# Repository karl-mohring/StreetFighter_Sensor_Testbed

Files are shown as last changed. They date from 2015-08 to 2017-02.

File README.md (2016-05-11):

# StreetFighter - Smart Streetlight Testbed


License (http://www.gnu.org/licenses/gpl-3.0.en.html)

# What is it?
StreetFighter is a smart cities sensor platform intended for mounting inside LED street lights. The platform includes sensors to monitor road usage, and can manage street light dimming to adapt the light level to real-time traffic.

Streetfighter installed in LED streetlight

## Why the stupid name?
- The main hardware platform of this project is the Arduino **Yun**.
- **Yun** (Lee) is a character from CAPCOM's **Street Fighter** franchise.
- Our sensor platform is intended for road-side deployment in **street** lights to **fight** energy waste
- It made sense to me...

# [Quick Start](https://github.com/Leenix/StreetFighter_Sensor_Testbed/wiki/Hardware-Installation)
The phrase "quick-start" can be misleading in hardware projects, but here's a list of things you'll need to set up this platform [(Full details in the Wiki)](https://github.com/Leenix/StreetFighter_Sensor_Testbed/wiki):
- Arduino Yun (with 4GB card) or Arduino Leonardo (for the non-logging, non-WiFi version)
- StreetFighter PCB
- Traffic sensors (sonar, lidar, PIR)
- Environmental sensors (temperature, humidity, illuminance, IR temperature, noise)
- Some kind of long-range network transceiver (XBee socket)

After you get all all that, you just need to populate the PCBs, wire up the sensors, configure the Yun software, build and upload the Arduino-side firmware, power the platform somehow, and then you're golden.

# [Features](https://github.com/Leenix/StreetFighter_Sensor_Testbed/wiki/Features)
## Traffic detection
- PIR sensor detects generic movements from vehicles, cyslists, and pedestrians
- Sonar/Lidar counts vehicles over a single lane

## Environmental monitoring
- Ambient temperature
- Relative humidity
- Illuminance
- Ambient noise
- Road temperature
- Road flood level

## Lamp health and control
- Luminaire temperature
- Power consumption
- Dimming interface

## Other
- Smartphone detection using Wifi and/or Bluetooth
- Public WiFi AP (if wired connection is provided)

# [Documentation](https://github.com/Leenix/StreetFighter_Sensor_Testbed/wiki)
- Full installation documentation can be found on the [Wiki](https://github.com/Leenix/StreetFighter_Sensor_Testbed/wiki)
- Code documentation is inside the code. No external reference just yet.

# [License](http://www.gnu.org/licenses/gpl-3.0.en.html)

This project is licensed under the terms of the GNU General Public License v3.0.

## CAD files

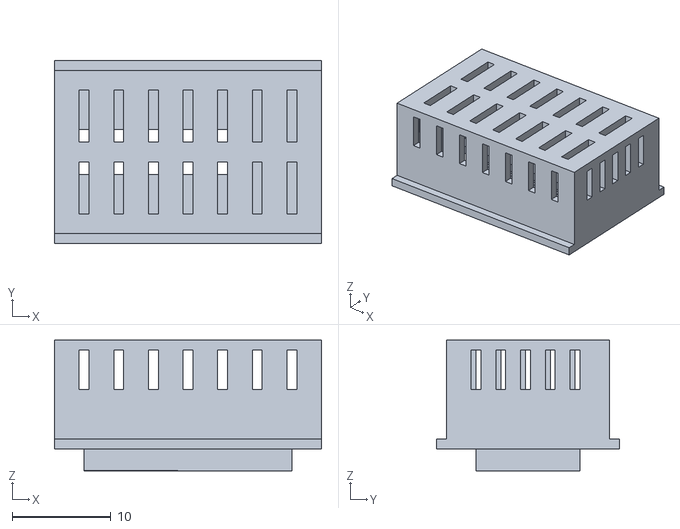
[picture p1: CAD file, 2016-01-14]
CAD/HIH screen.stl
27.0 x 18.5 x 13.2

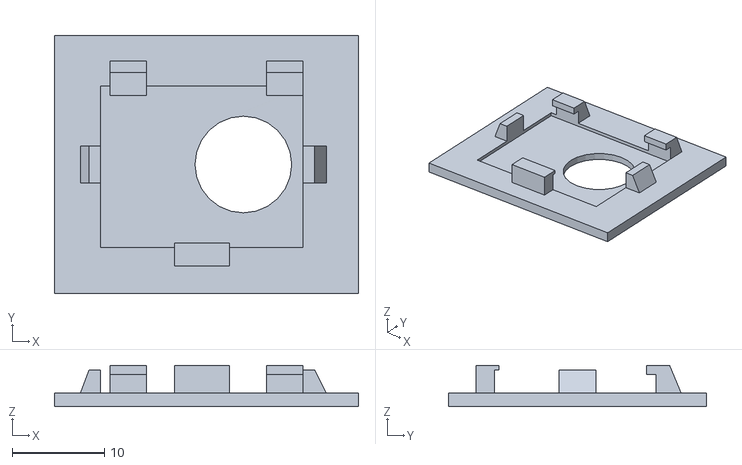
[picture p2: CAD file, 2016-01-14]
CAD/Individual sensor mounts/MIC mount.stl
33.0 x 28.0 x 4.50

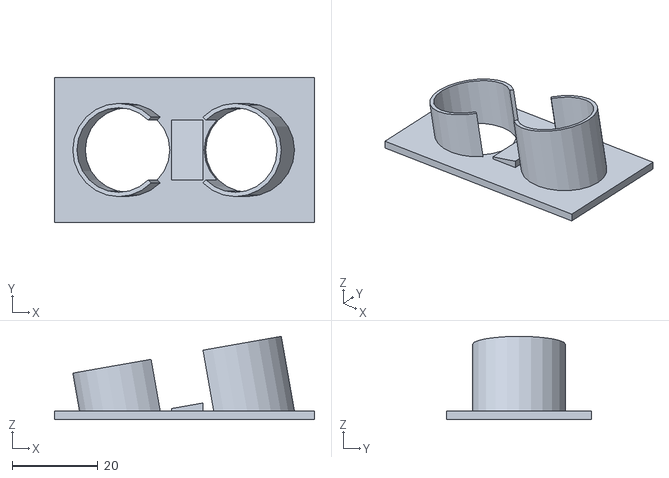
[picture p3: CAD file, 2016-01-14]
CAD/Luminaire Case/Lidar mount.stl
60.6 x 33.7 x 19.4

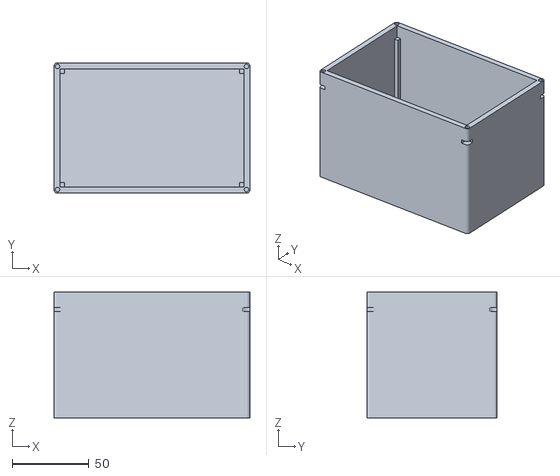
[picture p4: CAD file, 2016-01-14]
CAD/Individual sensor mounts/Streetfighter_casing.stl
128.0 x 85.0 x 82.0

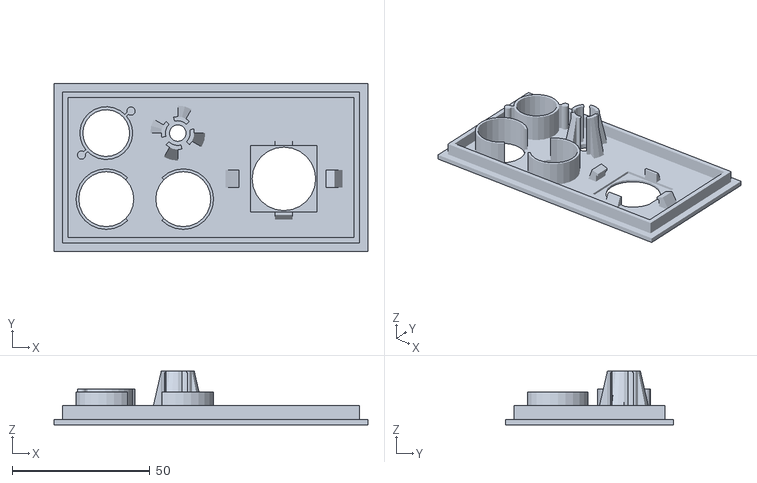
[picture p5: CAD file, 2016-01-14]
CAD/Luminaire Case/Big shell.stl
114.2 x 61.0 x 19.5

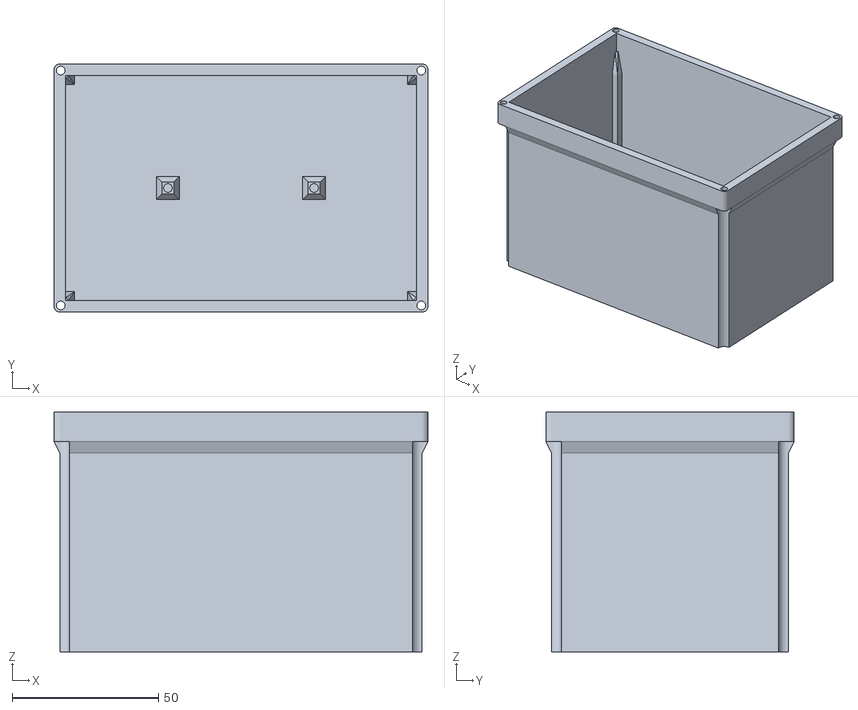
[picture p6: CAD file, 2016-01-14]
CAD/Individual sensor mounts/Streetfighter_casing-v3.stl
128.0 x 85.0 x 82.0

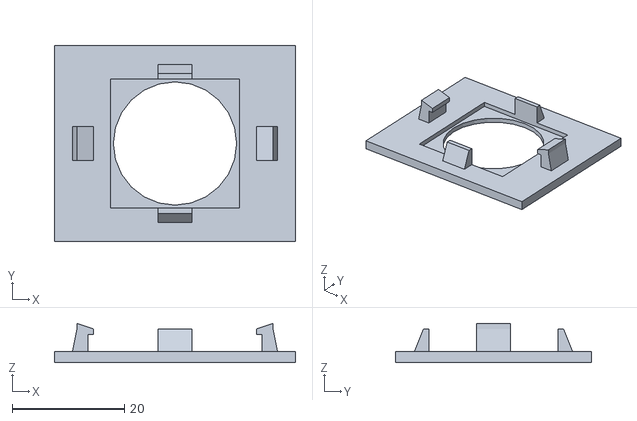
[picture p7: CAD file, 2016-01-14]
CAD/Individual sensor mounts/PIR Mount.stl
43.0 x 35.0 x 7.00

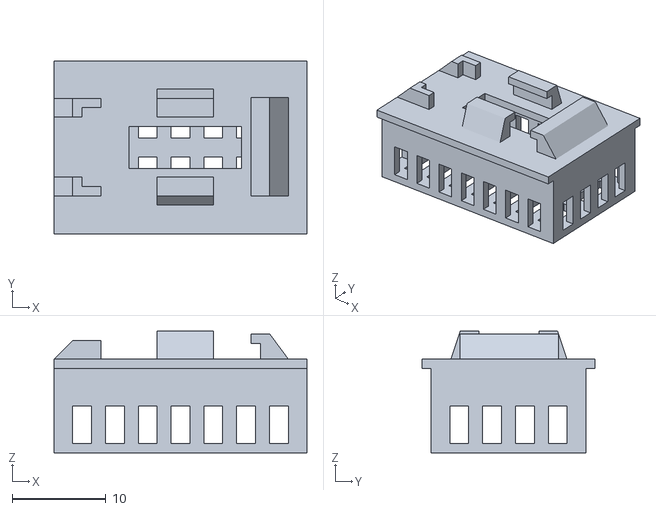
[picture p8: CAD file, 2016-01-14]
CAD/Individual sensor mounts/HIH screen.stl
27.0 x 18.5 x 13.0

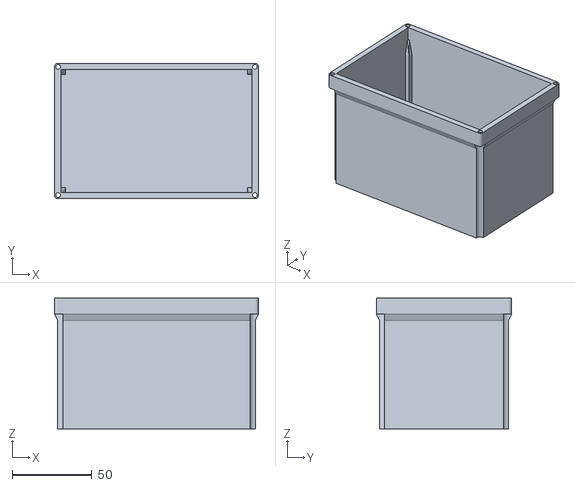
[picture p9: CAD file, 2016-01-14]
CAD/Individual sensor mounts/Streetfighter_casingv1.stl
128.0 x 85.0 x 82.0

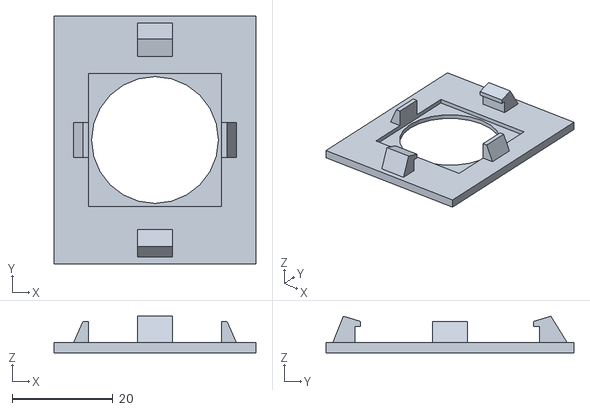
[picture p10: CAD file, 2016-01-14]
CAD/Individual sensor mounts/PIR Mount v2.stl
40.1 x 49.3 x 7.28

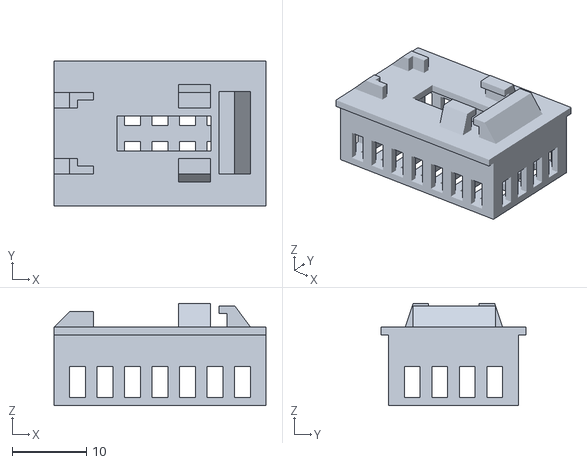
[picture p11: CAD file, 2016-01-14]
CAD/Individual sensor mounts/HIH4030 screen.stl
28.6 x 19.6 x 13.8

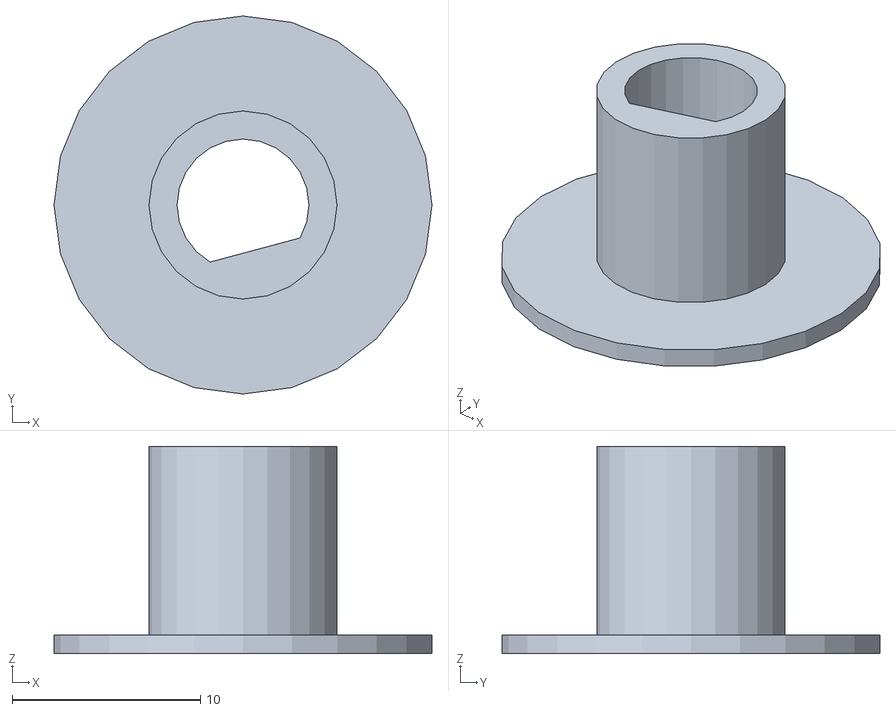
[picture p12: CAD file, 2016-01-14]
CAD/Individual sensor mounts/TMP36 Mount.stl
20.1 x 20.1 x 11.0

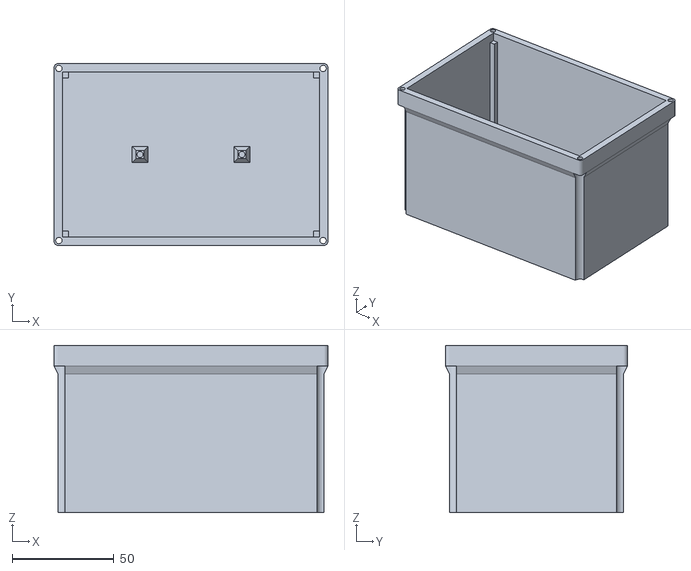
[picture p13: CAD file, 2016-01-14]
CAD/Individual sensor mounts/Streetfighter_casingv4.stl
134.4 x 89.3 x 82.0

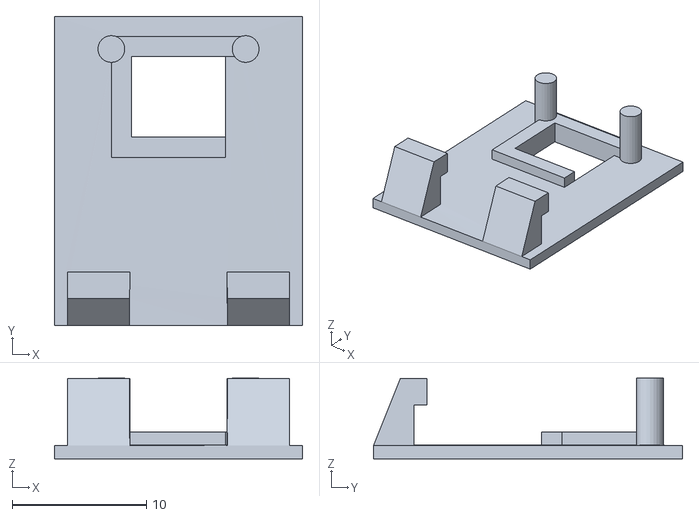
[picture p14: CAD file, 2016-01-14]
CAD/Individual sensor mounts/BH1750_mount.stl
18.5 x 23.0 x 6.02

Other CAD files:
CAD/Individual sensor mounts/Streetfighter_casing-v2.stl
CAD/Individual sensor mounts/BH1750_mount.skp
CAD/Individual sensor mounts/EZ0 Mount.skp
CAD/Individual sensor mounts/HIH screen.skp
CAD/Individual sensor mounts/HIH4030 screen.skp
CAD/Individual sensor mounts/Lidar mount.skp
CAD/Individual sensor mounts/MIC mount + spring.skp
CAD/Individual sensor mounts/MIC mount.skp
CAD/Individual sensor mounts/MIC mount1.skp
CAD/Individual sensor mounts/MLX90614 Mount.skp
CAD/Individual sensor mounts/PIR Mount.skp
CAD/Individual sensor mounts/Streetfighter_casing.skp
CAD/Individual sensor mounts/Streetfighter_casingv1.skp
CAD/Individual sensor mounts/Streetfighter_faceplate1.skp
CAD/Individual sensor mounts/Streetfighter_faceplate2.skp
CAD/Individual sensor mounts/TMP36 Mount.skp
CAD/Luminaire Mounting Plates.skp

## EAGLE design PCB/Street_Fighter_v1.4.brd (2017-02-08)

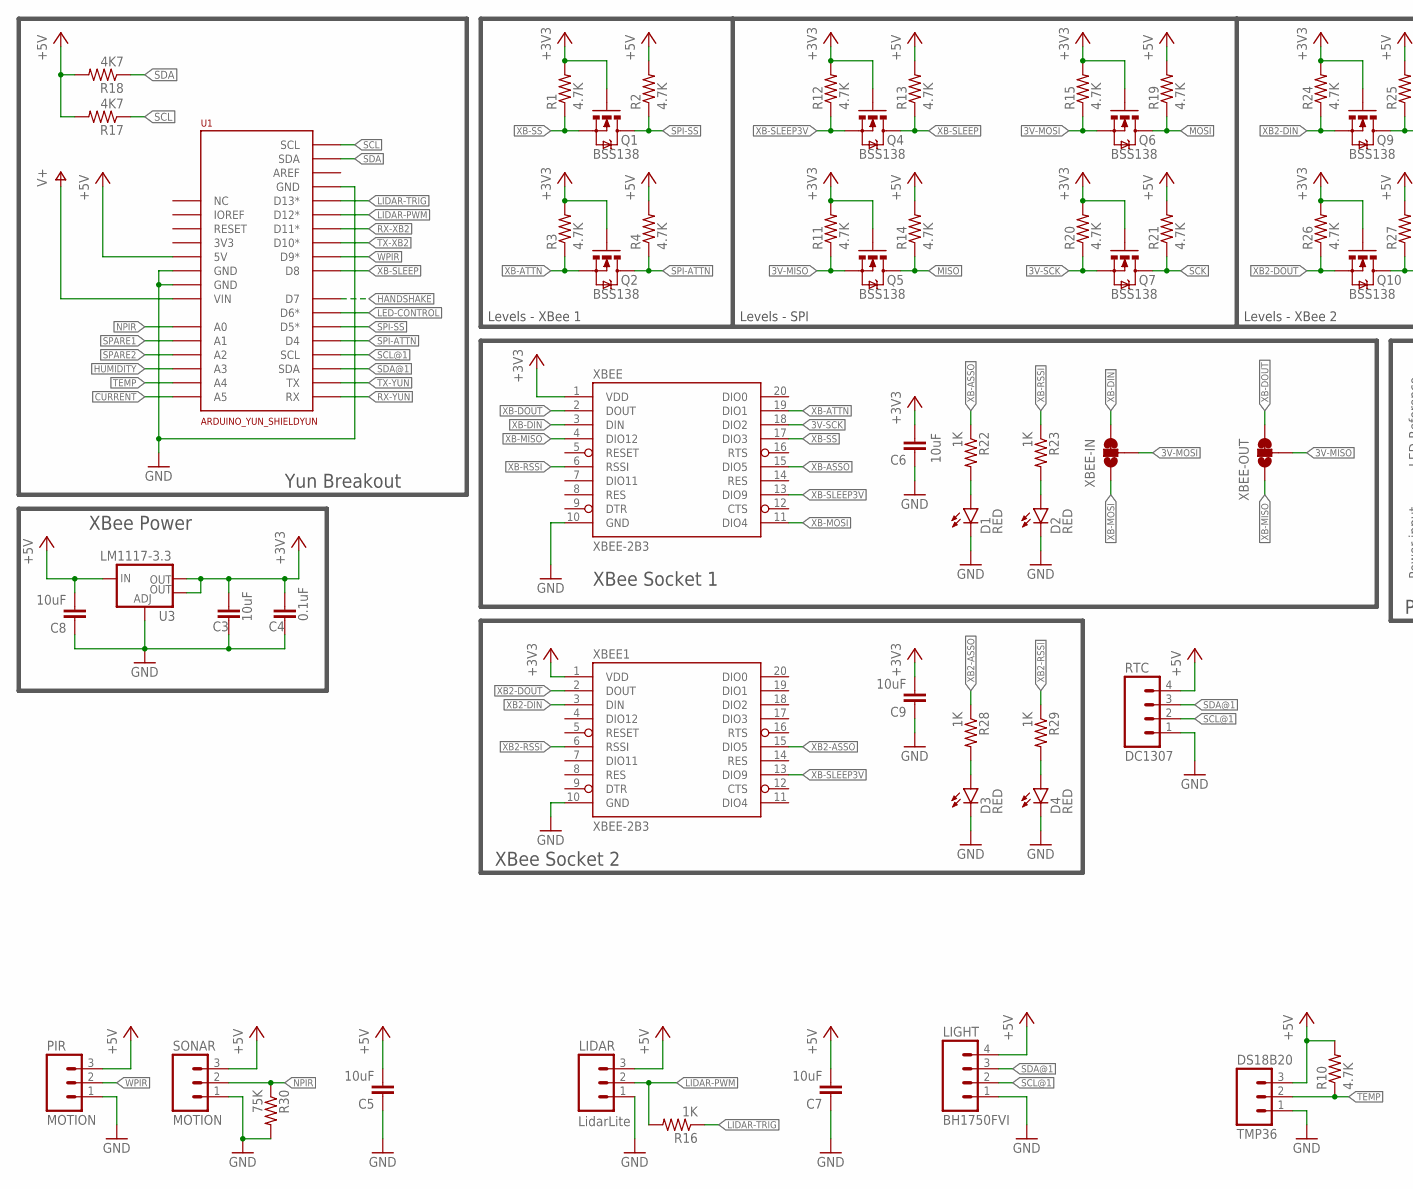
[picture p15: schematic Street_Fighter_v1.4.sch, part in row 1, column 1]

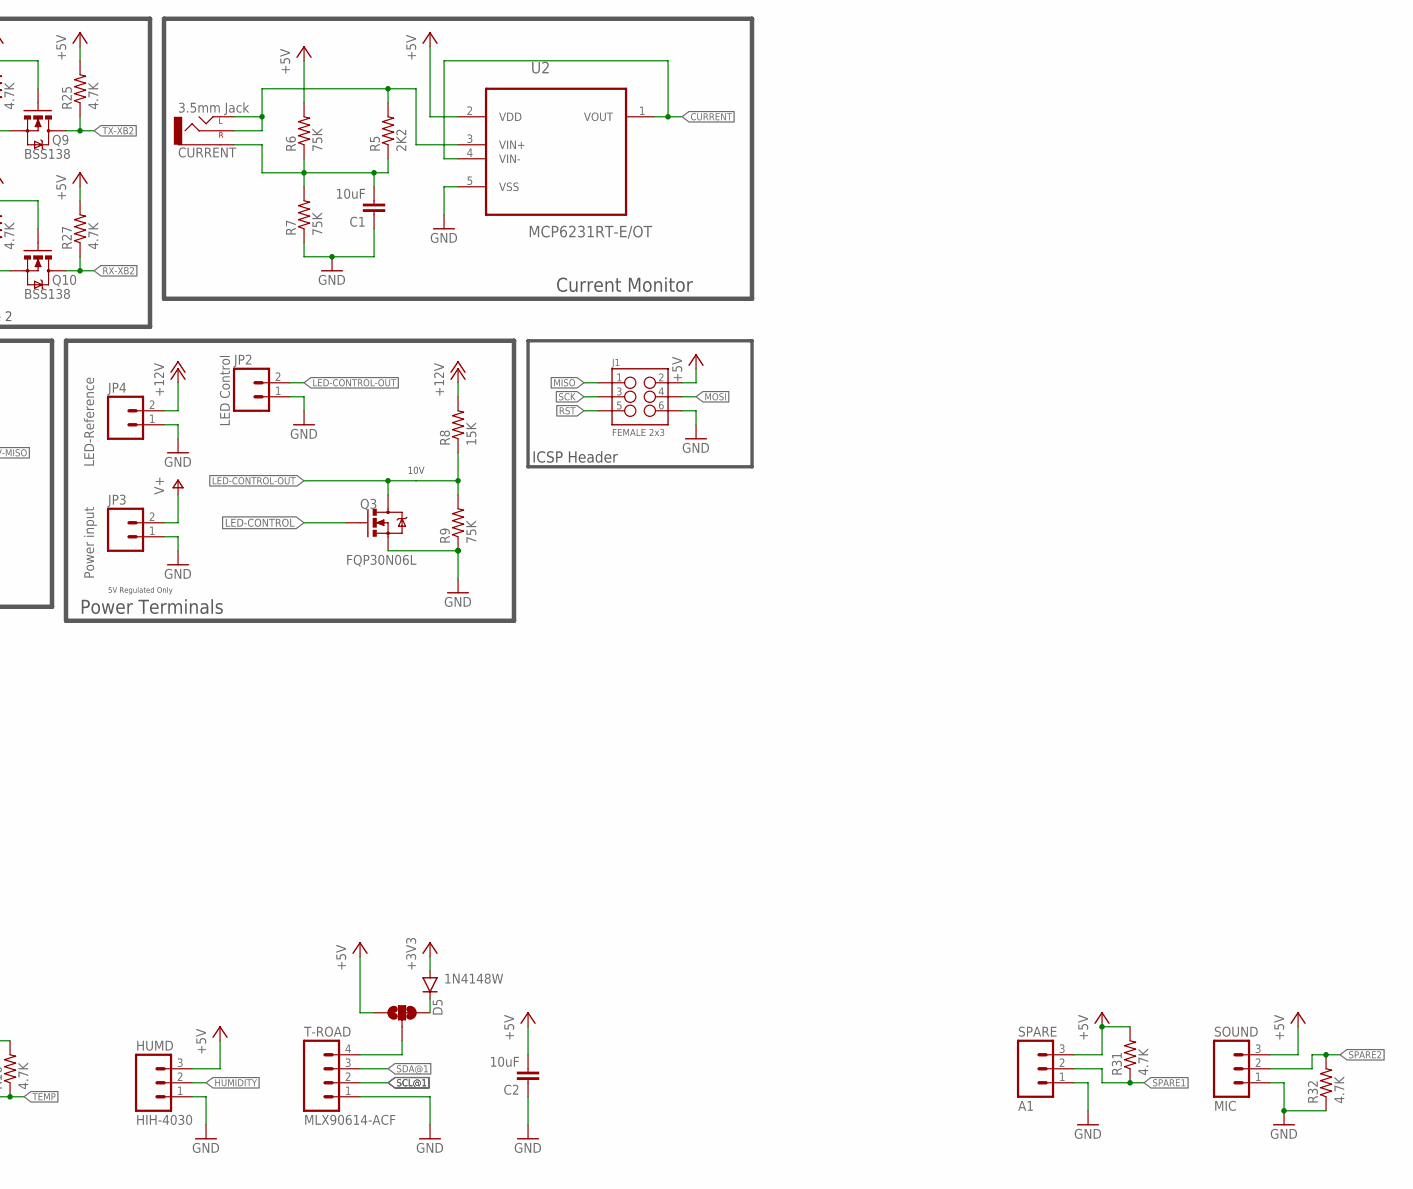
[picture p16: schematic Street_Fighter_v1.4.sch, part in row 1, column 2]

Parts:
C1, C2, C3, C5, C6, C7, C8, C9: 10uF; 1206
C4: 0.1uF; 1206
CURRENT: 3.5mm Jack; AUDIO-JACK
D1, D2, D3, D4: RED; LED-1206
D5: 1N4148W; SOD-123
DS18B20: TMP36; 1X03
HUMD: HIH-4030; 1X03
J1: FEMALE 2x3; 2X3
JP2: LED Control; 1X02_LONGPADS
JP3: Power input; 1X02_LONGPADS
JP4: LED-Reference; 1X02_LONGPADS
LIDAR: LidarLite; 1X03
LIGHT: BH1750FVI; 1X04
PIR: MOTION; 1X03
Q1, Q2, Q4, Q5, Q6, Q7, Q9, Q10: BSS138; SOT23
Q3: FQP30N06L; TO220V
R1, R2, R3, R4, R10, R11, R12, R13, R14, R15, R19, R20, R21, R24, R25, R26, R27, R31, R32: 4.7K; 1206
R5: 2K2; 1206
R6, R7, R9, R30: 75K; 1206
R8: 15K; 1206
R16, R22, R23, R28, R29: 1K; 1206
R17, R18: 4K7; 1206
RTC: DC1307; 1X04
SONAR: MOTION; 1X03
SOUND: MIC; 1X03
SPARE: A1; 1X03
T-ROAD: MLX90614-ACF; 1X04
U1: ARDUINO_YUN_SHIELDYUN; DUEMILANOVE_VIAS
U2: MCP6231RT-E/OT; SOT95P270X145-5N
U3: LM1117-3.3; SOT223
XBEE, XBEE1: XBEE-2B3; XBEE-SMD
XBEE-IN: JUMPER-PAD-3-2OF3_NC_BY_TRACE_SMALL; PAD-JUMPER-3-2OF3_NC_BY_TRACE_YES_SILK_FULL_BOX
XBEE-OUT, XBEE-OUT1: JUMPER-PAD-3-2OF3_NC_BY_TRACE_SMALL; PAD-JUMPER-3-2OF3_NC_BY_TRACE_YES_SILK_FULL_BOX

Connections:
3V3: U1.3V3
3V-MISO: Q5.2 (S), R11.1, XBEE-OUT.2
3V-MOSI: Q6.2 (S), R15.1, XBEE-IN.2
3V-SCK: Q7.2 (S), R20.1, XBEE.18 (DIO2)
+3V3: C3.2, C4.2, C6.2, C9.2, D5.A, Q1.1 (G), Q2.1 (G), Q4.1 (G), Q5.1 (G), Q6.1 (G), Q7.1 (G), Q9.1 (G), Q10.1 (G), R1.2, R3.2, R11.2, R12.2, R15.2, R20.2, R24.2, R26.2, U3.2 (OUT), U3.4 (OUT), XBEE.1 (VDD), XBEE1.1 (VDD)
+5V: C2.2, C5.2, C7.2, C8.2, DS18B20.3, HUMD.3, J1.2, LIDAR.3, LIGHT.4, PIR.3, R2.2, R4.2, R6.2, R10.2, R13.2, R14.2, R17.2, R18.2, R19.2, R21.2, R25.2, R27.2, R31.2, RTC.4, SONAR.3, SOUND.3, SPARE.3, U1.5V, U2.2 (VDD), U3.3 (IN), XBEE-OUT1.1
+12V: JP4.2, R8.2
CURRENT: U1.A5, U2.1 (VOUT), U2.4 (VIN-)
GND: C1.1, C2.1, C3.1, C4.1, C5.1, C6.1, C7.1, C8.1, C9.1, D1.C, D2.C, D3.C, D4.C, DS18B20.1, HUMD.1, J1.6, JP2.1, JP3.1, JP4.1, LIDAR.1, LIGHT.1, PIR.1, Q3.3 (S), R7.1, R9.1, R30.2, R32.1, RTC.1, SONAR.1, SOUND.1, SPARE.1, T-ROAD.1, U1.GND, U1.GND@0 (GND), U1.GND@1 (GND), U2.5 (VSS), U3.1 (ADJ), XBEE.10 (GND), XBEE1.10 (GND)
HANDSHAKE: U1.7 (D7)
HUMIDITY: HUMD.2, U1.A3
LED-CONTROL: Q3.1 (G), U1.6 (D6*)
LED-CONTROL-OUT: JP2.2, Q3.2 (D), R8.1, R9.2
LIDAR-PWM: LIDAR.2, R16.2, U1.12 (D12*)
LIDAR-TRIG: R16.1, U1.13 (D13*)
MISO: J1.1, Q5.3 (D), R14.1
MOSI: J1.4, Q6.3 (D), R19.1
unnamed: D1.A, R22.2
unnamed: CURRENT.RING (RIGHT), CURRENT.TIP (LEFT), R5.2, U2.3 (VIN+)
unnamed: D2.A, R23.2
unnamed: C1.2, CURRENT.SLEEVE, R5.1, R6.1, R7.2
unnamed: D3.A, R28.2
unnamed: D4.A, R29.2
unnamed: D5.C, XBEE-OUT1.3
unnamed: T-ROAD.4, XBEE-OUT1.2
NPIR: R30.1, SONAR.2, U1.A0
RST: J1.5
RX-XB2: Q10.3 (D), R27.1, U1.11 (D11*)
RX-YUN: U1.0 (RX)
SCK: J1.3, Q7.3 (D), R21.1
SCL: R17.1, U1.3@1 (SCL)
SCL@1: LIGHT.2, RTC.2, T-ROAD.2, U1.3 (SCL)
SDA: R18.1, U1.2@1 (SDA)
SDA@1: LIGHT.3, RTC.3, T-ROAD.3, U1.2 (SDA)
SPARE1: R31.1, SPARE.2, U1.A1
SPARE2: R32.2, SOUND.2, U1.A2
SPI-ATTN: Q2.3 (D), R4.1, U1.D4
SPI-SS: Q1.3 (D), R2.1, U1.5 (D5*)
TEMP: DS18B20.2, R10.1, U1.A4
TX-XB2: Q9.3 (D), R25.1, U1.10 (D10*)
TX-YUN: U1.1 (TX)
V+: JP3.2, U1.VIN
WPIR: PIR.2, U1.9 (D9*)
XB2-ASSO: R28.1, XBEE1.15 (DIO5)
XB2-DIN: Q9.2 (S), R24.1, XBEE1.3 (DIN)
XB2-DOUT: Q10.2 (S), R26.1, XBEE1.2 (DOUT)
XB2-RSSI: R29.1, XBEE1.6 (RSSI)
XB-ASSO: R22.1, XBEE.15 (DIO5)
XB-ATTN: Q2.2 (S), R3.1, XBEE.19 (DIO1)
XB-DIN: XBEE.3 (DIN), XBEE-IN.3
XB-DOUT: XBEE.2 (DOUT), XBEE-OUT.3
XB-MISO: XBEE.4 (DIO12), XBEE-OUT.1
XB-MOSI: XBEE.11 (DIO4), XBEE-IN.1
XB-RSSI: R23.1, XBEE.6 (RSSI)
XB-SLEEP: Q4.3 (D), R13.1, U1.8 (D8)
XB-SLEEP3V: Q4.2 (S), R12.1, XBEE.13 (DIO9), XBEE1.13 (DIO9)
XB-SS: Q1.2 (S), R1.1, XBEE.17 (DIO3)

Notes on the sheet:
10V
Power Terminals
Yun Breakout
Current Monitor
XBee Socket 1
5V Regulated Only
Levels - XBee 1
Levels - SPI
Levels - XBee 2
XBee Power
XBee Socket 2
ICSP Header

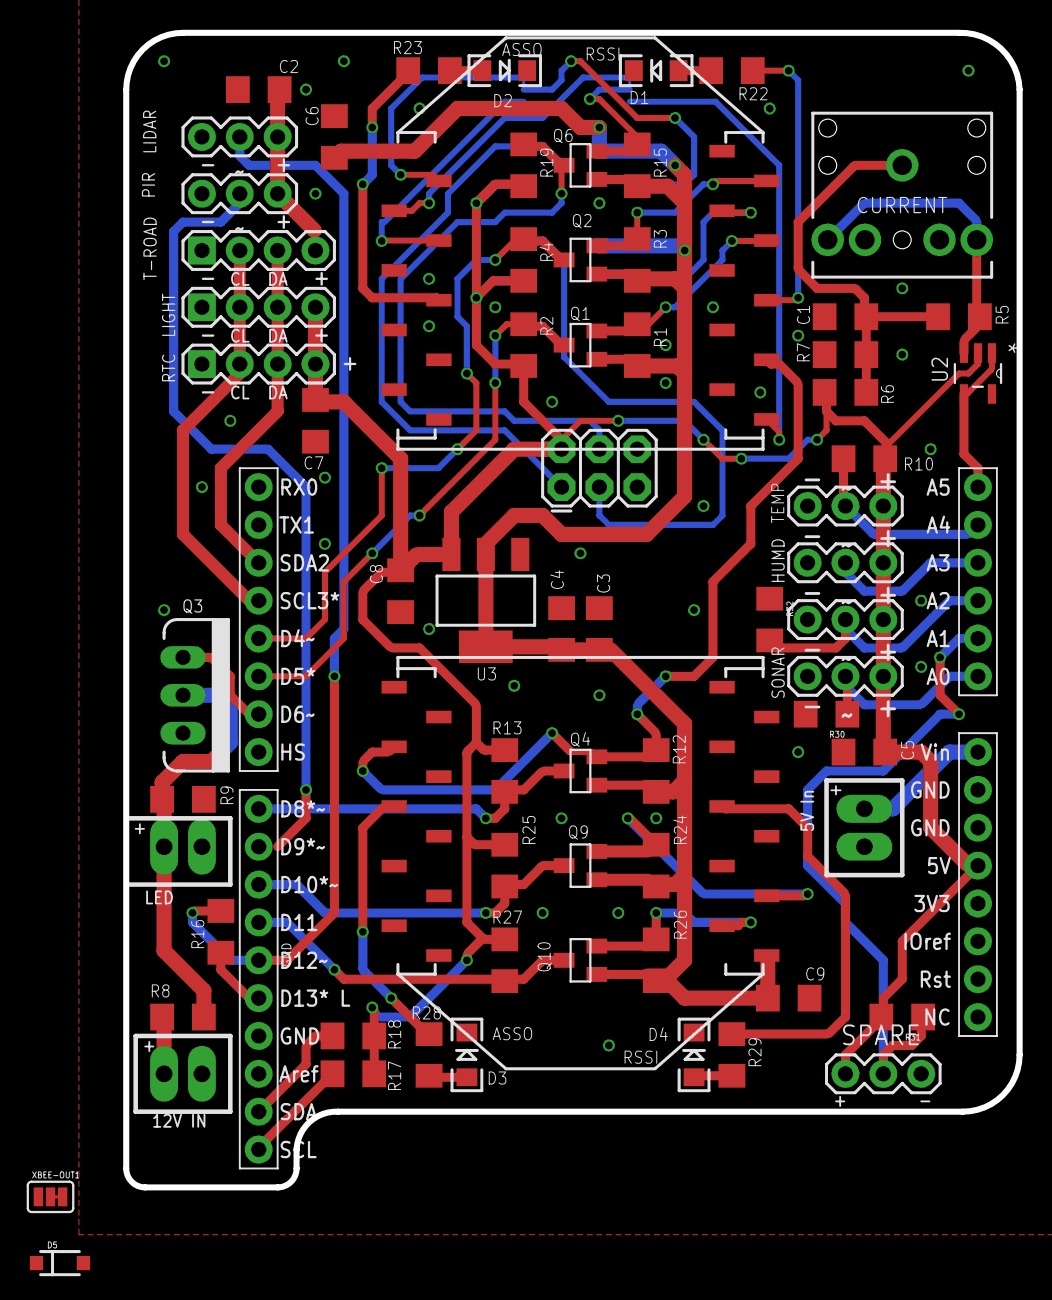
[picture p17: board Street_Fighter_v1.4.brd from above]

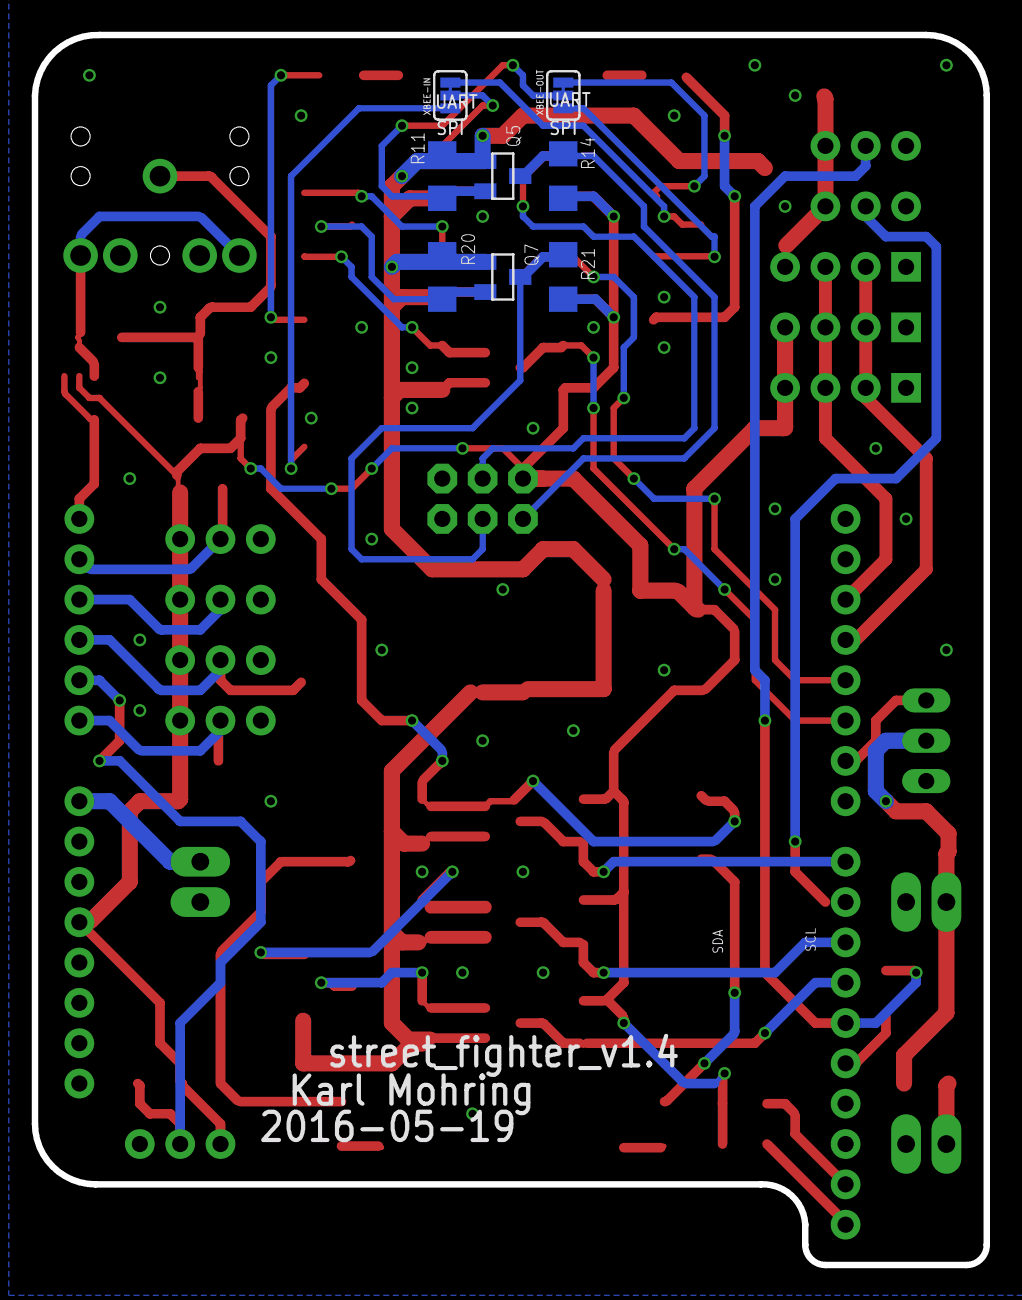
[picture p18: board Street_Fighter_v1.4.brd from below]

Board: 2 copper layers, 59.9 x 77.5 mm, 78 parts (8 on the bottom side), 52 nets.

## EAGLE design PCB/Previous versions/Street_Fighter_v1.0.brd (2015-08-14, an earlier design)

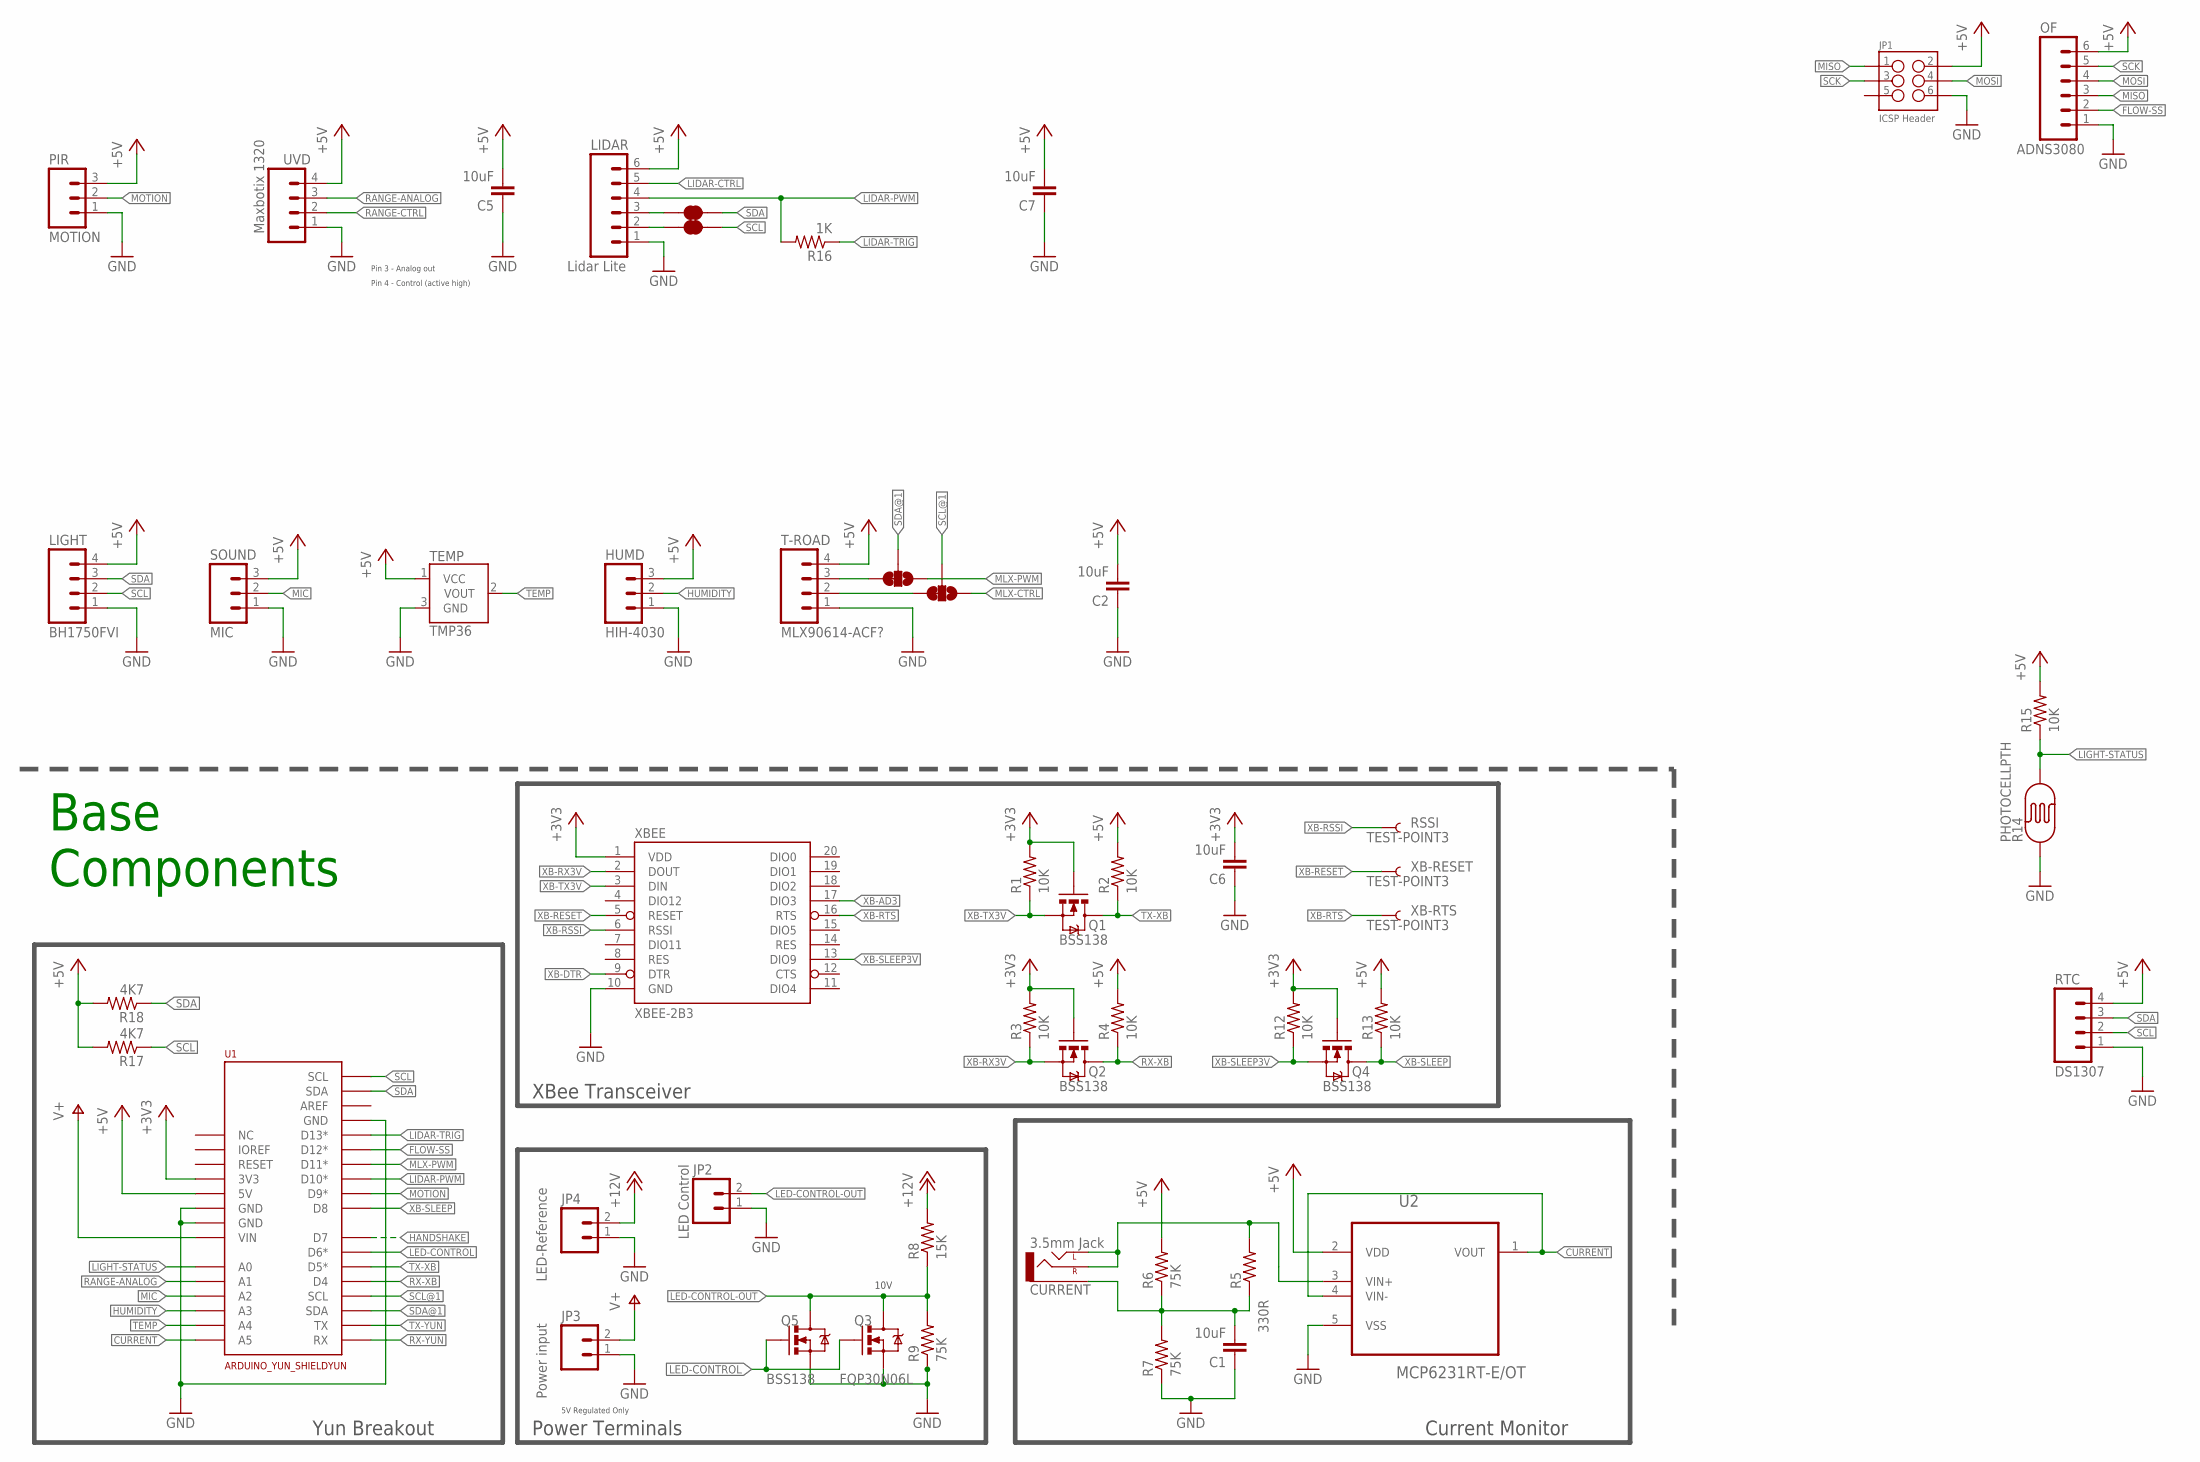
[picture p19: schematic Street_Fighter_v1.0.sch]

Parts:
C1, C2, C5, C6, C7: 10uF; 1206
CURRENT: 3.5mm Jack; AUDIO-JACK
HUMD: HIH-4030; 1X03
JP1: ICSP Header; 2X3
JP2: LED Control; 1X02_LONGPADS
JP3: Power input; 1X02_LONGPADS
JP4: LED-Reference; 1X02_LONGPADS
LIDAR: Lidar Lite; 1X06
LIGHT: BH1750FVI; 1X04
OF: ADNS3080; 1X06
PIR: MOTION; 1X03
Q1, Q2, Q4, Q5: BSS138; SOT23
Q3: FQP30N06L; TO220V
R1, R2, R3, R4, R12, R13, R15: 10K; 1206
R5: 330R; 1206
R6, R7, R9: 75K; 1206
R8: 15K; 1206
R14: PHOTOCELLPTH; PHOTOCELL
R16: 1K; 1206
R17, R18: 4K7; 1206
RSSI: TEST-POINT3; PAD.03X.03
RTC: DS1307; 1X04
SJ1, SJ2: JUMPER-PAD-2-NC_BY_TRACE; PAD-JUMPER-2-NC_BY_TRACE_YES_SILK
SJ3, SJ4: JUMPER-PAD-3-2OF3_NC_BY_TRACE_SMALL; PAD-JUMPER-3-2OF3_NC_BY_TRACE_YES_SILK_FULL_BOX
SOUND: MIC; 1X03
T-ROAD: MLX90614-ACF?; 1X04
TEMP: TMP36; TO-92
U1: ARDUINO_YUN_SHIELDYUN; DUEMILANOVE_VIAS
U2: MCP6231RT-E/OT; SOT95P270X145-5N
UVD: Maxbotix 1320; 1X04
XB-RESET: TEST-POINT3; PAD.03X.03
XB-RTS: TEST-POINT3; PAD.03X.03
XBEE: XBEE-2B3; XBEE-SMD

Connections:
+3V3: C6.2, Q1.1 (G), Q2.1 (G), Q4.1 (G), R1.2, R3.2, R12.2, U1.3V3, XBEE.1 (VDD)
+5V: C2.2, C5.2, C7.2, HUMD.3, JP1.2, LIDAR.6, LIGHT.4, OF.6, PIR.3, R2.2, R4.2, R6.2, R13.2, R15.2, R17.2, R18.2, RTC.4, SOUND.3, T-ROAD.4, TEMP.1 (VCC), U1.5V, U2.2 (VDD), UVD.4
+12V: JP4.2, R8.2
CURRENT: U1.A5, U2.1 (VOUT), U2.4 (VIN-)
FLOW-SS: OF.2, U1.12 (D12*)
GND: C1.1, C2.1, C5.1, C6.1, C7.1, HUMD.1, JP1.6, JP2.1, JP3.1, JP4.1, LIDAR.1, LIGHT.1, OF.1, PIR.1, Q3.3 (S), Q5.2 (S), R7.1, R9.1, R14.1, RTC.1, SOUND.1, T-ROAD.1, TEMP.3 (GND), U1.GND, U1.GND@0 (GND), U1.GND@1 (GND), U2.5 (VSS), UVD.1, XBEE.10 (GND)
HANDSHAKE: U1.7 (D7)
HUMIDITY: HUMD.2, U1.A3
LED-CONTROL: Q3.1 (G), Q5.1 (G), U1.6 (D6*)
LED-CONTROL-OUT: JP2.2, Q3.2 (D), Q5.3 (D), R8.1, R9.2
LIDAR-CTRL: LIDAR.5
LIDAR-PWM: LIDAR.4, R16.2, U1.10 (D10*)
LIDAR-TRIG: R16.1, U1.13 (D13*)
LIGHT-STATUS: R14.2, R15.1, U1.A0
MIC: SOUND.2, U1.A2
MISO: JP1.1, OF.3
MLX-CTRL: SJ4.1
MLX-PWM: SJ3.1, U1.11 (D11*)
MOSI: JP1.4, OF.4
MOTION: PIR.2, U1.9 (D9*)
unnamed: CURRENT.RING (RIGHT), CURRENT.TIP (LEFT), R5.2, U2.3 (VIN+)
unnamed: C1.2, CURRENT.SLEEVE, R5.1, R6.1, R7.2
RANGE-ANALOG: U1.A1, UVD.3
RANGE-CTRL: UVD.2
RX-XB: Q2.3 (D), R4.1, U1.D4
RX-YUN: U1.0 (RX)
SCK: JP1.3, OF.5
SCL: LIDAR.2, LIGHT.2, R17.1, RTC.2, SJ2.1, SJ2.2, U1.3@1 (SCL)
SCL@1: SJ4.2, SJ4.3, T-ROAD.2, U1.3 (SCL)
SDA: LIDAR.3, LIGHT.3, R18.1, RTC.3, SJ1.1, SJ1.2, U1.2@1 (SDA)
SDA@1: SJ3.2, SJ3.3, T-ROAD.3, U1.2 (SDA)
TEMP: TEMP.2 (VOUT), U1.A4
TX-XB: Q1.3 (D), R2.1, U1.5 (D5*)
TX-YUN: U1.1 (TX)
V+: JP3.2, U1.VIN
XB-AD3: XBEE.17 (DIO3)
XB-DTR: XBEE.9 (DTR)
XB-RESET: XB-RESET.P$1, XBEE.5 (RESET)
XB-RSSI: RSSI.P$1, XBEE.6 (RSSI)
XB-RTS: XB-RTS.P$1, XBEE.16 (RTS)
XB-RX3V: Q2.2 (S), R3.1, XBEE.2 (DOUT)
XB-SLEEP: Q4.3 (D), R13.1, U1.8 (D8)
XB-SLEEP3V: Q4.2 (S), R12.1, XBEE.13 (DIO9)
XB-TX3V: Q1.2 (S), R1.1, XBEE.3 (DIN)

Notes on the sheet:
10V
Pin 3 - Analog out
Pin 4 - Control (active high)
Power Terminals
Yun Breakout
Current Monitor
XBee Transceiver
Base Components
5V Regulated Only

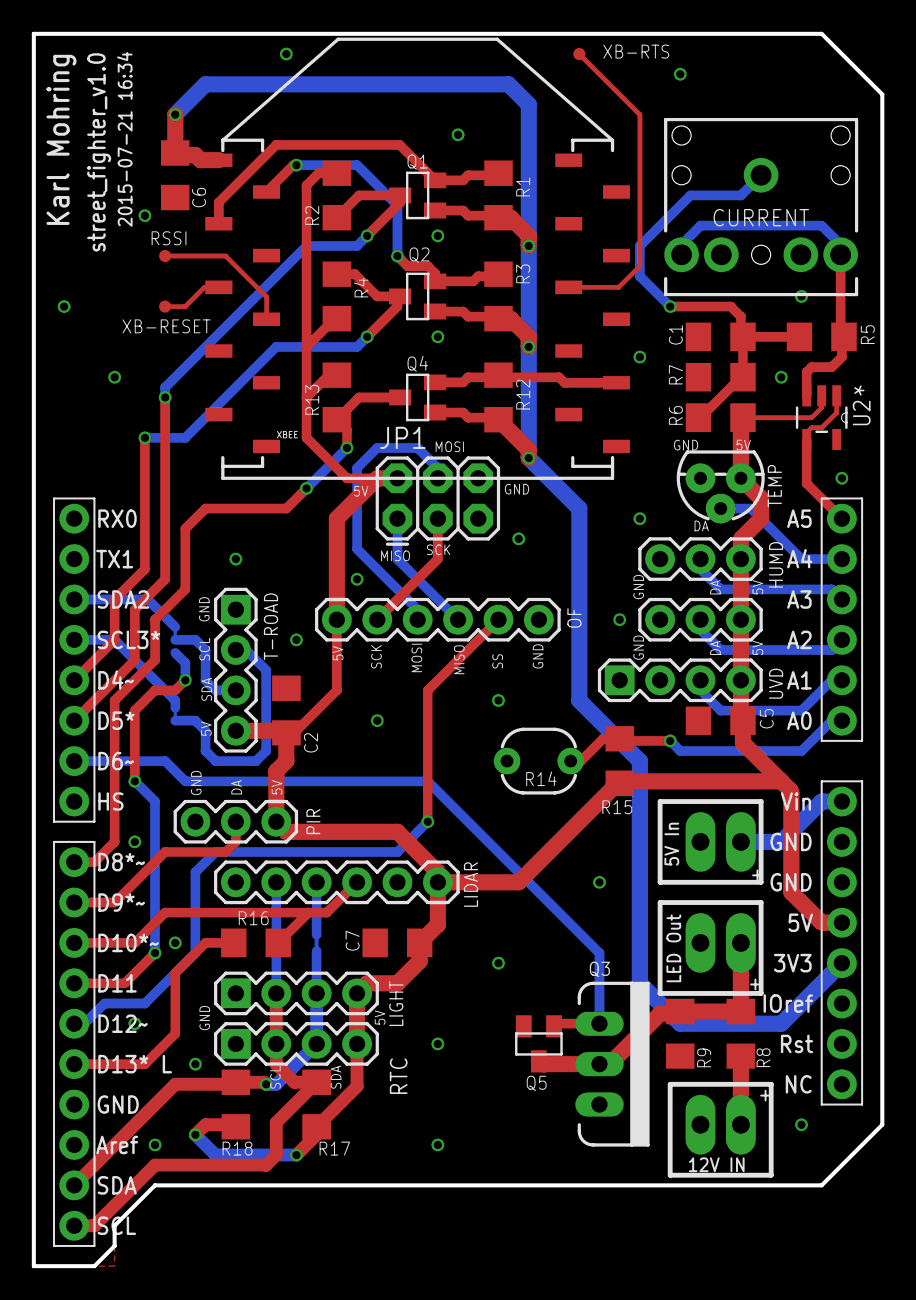
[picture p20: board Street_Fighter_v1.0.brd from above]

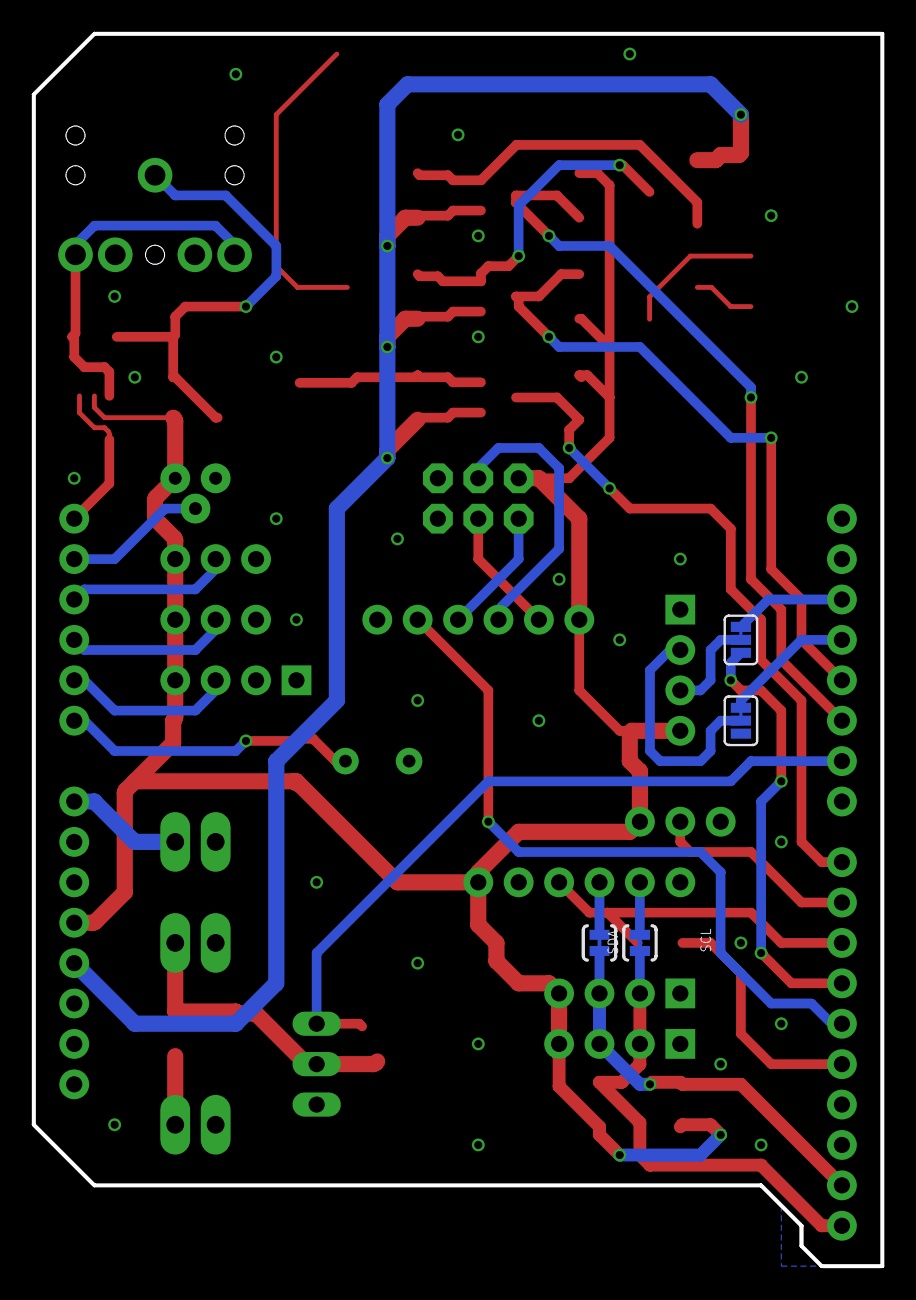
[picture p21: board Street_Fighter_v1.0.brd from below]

Board: 2 copper layers, 53.3 x 77.5 mm, 51 parts (4 on the bottom side), 36 nets.

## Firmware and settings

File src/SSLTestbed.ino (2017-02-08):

#include <Arduino.h>
#include <Wire.h>
#include <SoftwareSerial.h>
#include <RTClib.h>

#include <ArduinoJson.h>
#include <LIDARduino.h>
#include "ProgmemString.h"
#include "Logging.h"
#include "SimpleTimer.h"

#include "config.h"

// XBee - in Transparent (Serial bridge) mode
SoftwareSerial xbee_bridge(COMM_1_RX, COMM_1_TX);

// Bluetooth module
SoftwareSerial bluetooth(COMM_2_RX, COMM_2_TX);

// Traffic Sensors
LIDAR_Lite_PWM lidar(LIDAR_TRIGGER_PIN, LIDAR_PWM_PIN);
static int successive_lidar_detections = 0;

// Misc
RTC_DS3231 rtc;

char bluetooth_buffer[BLUETOOTH_BUFFER_SIZE];
int bluetooth_index = 0;
bool bluetooth_recording = false;

// Timers
SimpleTimer timer;

// PIR variables
bool cooldown_active[NUM_PIR_SENSORS];
bool motion_status[NUM_PIR_SENSORS];
unsigned long motion_start_time[NUM_PIR_SENSORS];

// Objects
SensorEntry data;

////////////////////////////////////////////////////////////////////////////////
/* Arduino main functions */

void setup() {
  /**
  * Startup code - Run once
  */
  data.id = UNIT_NAME;
  data.version = SSL_TESTBED_VERSION;

  start_yun_serial();
  Log.Info(P("Traffic Counter - ver %d"), SSL_TESTBED_VERSION);

  if (REAL_TIME_CLOCK_ENABLED) {
    start_rtc();
  }

  if (XBEE_ENABLED) {
    start_xbee();
  }

  start_sensors();

  if (BLUETOOTH_ENABLED) {
    start_bluetooth_scanner();
  }
}

void loop() {
  /**
  * Main loop - run forever
  */
  timer.run();
}

////////////////////////////////////////////////////////////////////////////////
/* Yun Serial */

void start_yun_serial() {
  /**
  * Set up the Arduino-Linux serial bridge
  * Serial output from the Arduino is disabled until the Yun has finished
  * booting
  * The serial can be accessed safely after the boot debug finishes.
  * Any serial transmission during this time would halt start-up, which would
  * suck.
  */

  // Set up the handshake pin
  pinMode(YUN_HANDSHAKE_PIN, INPUT_PULLUP);
  pinMode(LED_BUILTIN, OUTPUT);
  digitalWrite(LED_BUILTIN, LOW);

  // Give a delay for the AR9331 to reset, in case we were reset as part of a
  // reboot command.
  // See http://playground.arduino.cc/Hardware/Yun#rebootStability, case 3.
  delay(YUN_BOOT_DELAY);

  // If the system is booting, wait for UBoot to finish (Shamelessly adapted
  // from Bridge.cpp)
  USE_SERIAL.begin(YUN_LINUX_BAUD_RATE);
  do {
    while (USE_SERIAL.available() > 0) {
      USE_SERIAL.read();
    }
    delay(YUN_BOOT_DELAY);
  } while (USE_SERIAL.available() > 0);
  USE_SERIAL.end();

  // Check the initial state of the handshake pin (LOW == Ready)
  boot_status_change_ISR();

  USE_SERIAL.begin(SERIAL_BAUD);

  // Listen on the handshake pin for any changes
  attachInterrupt(4, boot_status_change_ISR, CHANGE);
}

void boot_status_change_ISR() {
  /**
  * ISR - Called when the handshake pin (D7) is changed by the AR9331
  * Toggle serial output depending on the boot state of the Yun.
  * If the handshake pin changes, the boot status of the Yun has changed.
  * Handshake == LOW means the linux environment is ready for serial
  */
  bool linux_busy = digitalRead(YUN_HANDSHAKE_PIN);

  if (linux_busy) {
    // Disable log output until Linux boots
    Log.Init(LOG_LEVEL_NOOUTPUT, &USE_SERIAL);
  } else {
    Log.Init(LOGGER_LEVEL, &USE_SERIAL);
  }
}

////////////////////////////////////////////////////////////////////////////////
/* XBee Comms */

void start_xbee() {
  /**
  * Start up xbee communication
  * XBee is connected to software serial
  * XBee communication uses AT mode - which just uses the XBee as a serial
  * bridge.
  * There is no packet handling and all data travels one way: out
  */
  xbee_bridge.begin(XBEE_BAUD);
}

////////////////////////////////////////////////////////////////////////////////
/* Printing */

void start_sensors() {
  /**
  * Enable and configure the sensor suite for reading.
  * A timer is started to regularly print sensor data
  */

  if (LIDAR_ENABLED) {
    start_lidar();
  }

  if (PIR_ENABLED) {
    start_pir();
  }

  // Start timer for regular entry transmission
  timer.setInterval(PRINT_INTERVAL, print_regular_entry);
}

void print_regular_entry() {
  /**
  * Print a normal data entry
  * Regular entries are triggered by timer, rather than sensor
  * The traffic event flag is 'off'
  */
  data.event_flag = false;
  print_data();
}

void trigger_traffic_event() {
  /**
  * Print a data entry
  * The traffic event flag is enabled
  */
  data.event_flag = true;
  print_data();
}

void print_data() {
  /**
  * Print the current traffic counts and info to Serial
  */
  if (REAL_TIME_CLOCK_ENABLED) {
    update_timestamp();
  }

  print_json_string();
}

void print_json_string() {
  /**
  * Format the data packet into a JSON string
  * @return JSON-formatted string containing selected data
  */
  StaticJsonBuffer<COMM_BUFFER_SIZE> print_buffer;
  JsonObject &entry = print_buffer.createObject();

  entry["ver"] = data.version;
  entry["id"] = data.id;
  entry["npir"] = data.pir_count[PIR_NARROW];
  entry["wpir_l"] = data.pir_count[PIR_WIDE_LEFT];
  entry["wpir_r"] = data.pir_count[PIR_WIDE_RIGHT];
  entry["cool_n"] = data.pir_in_cooldown[PIR_NARROW];
  entry["cool_l"] = data.pir_in_cooldown[PIR_WIDE_LEFT];
  entry["cool_r"] = data.pir_in_cooldown[PIR_WIDE_RIGHT];
  entry["lidar"] = data.lidar_count;
  entry["l_range"] = data.lidar_range;
  entry["timestamp"] = data.timestamp;

  if (Log.getLevel() > LOG_LEVEL_NOOUTPUT) {
    USE_SERIAL.print(PACKET_START);
    entry.printTo(USE_SERIAL);
    USE_SERIAL.println(PACKET_END);
    USE_SERIAL.flush();
  }

  if (XBEE_ENABLED) {
    // Push the JSON string to XBee as well
    xbee_bridge.print(PACKET_START);
    entry.printTo(xbee_bridge);
    xbee_bridge.print(PACKET_END);
  }
}

////////////////////////////////////////////////////////////////////////////////
/* PIR */

void start_pir() {
  /**
  * Start the PIR motion sensor for motion detections
  */

  // Set up input pins for PIR sensors
  for (int i = 0; i < NUM_PIR_SENSORS; i++) {
    pinMode(PIR_PINS[i], INPUT);
    motion_status[i] = false;
    motion_start_time[i] = 0;
    data.pir_count[i] = 0;
  }

  // Stop everything until the PIR sensor has had a chance to settle
  warm_up_pir_sensors();

  // Start up regular reads
  timer.setInterval(CHECK_MOTION_INTERVAL, update_pir);
  Log.Info(P("Motion started"));

  update_pir();
}

void warm_up_pir_sensors(){
    /**
    * Halt the system until the PIR sensors have had a chance to start.
    * The downtime is goverened by the MOTION_INITIALISATION_TIME variable
    * Default: 10 seconds
    */
    Log.Info(P("Calibrating motion sensor - wait %d ms"), MOTION_INITIALISATION_TIME);

    for (long i = 0; i < MOTION_INITIALISATION_TIME;
         i += (MOTION_INITIALISATION_TIME / MOTION_INITIALISATION_INTERVALS)) {
      Log.Debug(P("Motion sensor calibration: %d ms remaining..."), (MOTION_INITIALISATION_TIME - i));
      USE_SERIAL.flush();
      delay(MOTION_INITIALISATION_TIME / MOTION_INITIALISATION_INTERVALS);
    }
}

void update_pir() {
  /**
  * Check the PIR sensor for detected movement
  * The sensor will output HIGH when motion is detected.
  * Detections will hold the detection status HIGH until the cool-down has
  * lapsed (default: 2s)
  */

  // Check all PIR sensors (both narrow and wide)
  for (int i = 0; i < NUM_PIR_SENSORS; i++) {

    // Check cooldown status
    if (data.pir_in_cooldown[i]) {
      if (millis() - motion_start_time[i] > PIR_COOLDOWNS[i]) {
        data.pir_in_cooldown[i] = false;
      }
    }

    // Check for motion if not in cooldown
    if (!data.pir_in_cooldown[i]) {
      if (digitalRead(PIR_PINS[i]) == PIR_ACTIVE_STATES[i]) {
        if (!PIR_MUST_GO_LOW_BETWEEN_TRIGGERS || !motion_status[i]) {

          // If motion detected, increment the count (and do all the extra bits)
          motion_status[i] = true;
          motion_start_time[i] = millis();
          data.pir_in_cooldown[i] = true;
          increment_pir_count(i);
          Log.Info("Sensor %d triggered. Count: %l", i, data.pir_count[i]);
          trigger_traffic_event();
        }

        else {
          if (motion_status[i]) {
            motion_status[i] = false;
          }
        }
      }
    }
  }
}

void increment_pir_count(int sensor_num) {

    // Narrow sensor detection
    if (PIR_TYPES[sensor_num] == PIR_NARROW) {
        increment_narrow_pir(sensor_num);
    }

    // Wide sensor detection
    else{
        increment_wide_pir(sensor_num);
    }
}

void increment_narrow_pir(int sensor_num){
    // If we're dealing with the narrow sensor, the count should only increment if a wide is already triggered
    bool wide_triggered = false;
    for (int i = 0; i < NUM_PIR_SENSORS; i++) {
        if (PIR_TYPES[i] == PIR_WIDE && data.pir_in_cooldown[i]){
            wide_triggered = true;
        }
    }
    if (wide_triggered){
        data.pir_count[sensor_num]++;
    }
}

void increment_wide_pir(int sensor_num){
    // The wide sensors don't have any self-validation
    data.pir_count[sensor_num]++;

    // However, we still want to check if there's been some flow between the sensors
    unsigned long other_start = 2 * PIR_MAX_FLOW_DELAY;
    unsigned long now = millis();

    // Find out if/when another wide sensor was active
    for (int i = 0; i < NUM_PIR_SENSORS; i++) {
        Log.Debug(P("I: %d %T; Wide? %T; Cooldown? %T"), i, i == sensor_num, PIR_TYPES[i] == PIR_WIDE, data.pir_in_cooldown[i]);
        if (i != sensor_num && PIR_TYPES[i] == PIR_WIDE && data.pir_in_cooldown[i]) {
            Log.Debug(P("Checking sensor %d"), i);

            unsigned long time_since_trigger = now - motion_start_time[i];
            if (other_start > time_since_trigger){
                other_start = time_since_trigger;
            }
        }
    }

    if (PIR_MIN_FLOW_DELAY < other_start && other_start < PIR_MAX_FLOW_DELAY) {
        if (sensor_num == PIR_WIDE_LEFT) {
            // Object travelled from right to left
            Log.Info(P("Leftward travel"));
        }
        else{
            // Object travelled from left to right
            Log.Info(P("Rightward travel"));
        }
    }
}

////////////////////////////////////////////////////////////////////////////////
/* Lidar */

void start_lidar() {
  /**
  * Start the rangefinder sensor
  * A baseline range (to the ground or static surrounds) is established for
  * comparing against new measuremets.
  */
  pinMode(LIDAR_TRIGGER_PIN, INPUT);
  pinMode(LIDAR_PWM_PIN, INPUT);
  lidar.begin();

  Log.Debug(P("Lidar - Establishing baseline range..."));
  data.lidar_baseline = get_lidar_baseline(BASELINE_VARIANCE_THRESHOLD);

  timer.setInterval(LIDAR_CHECK_RANGE_INTERVAL, update_lidar);
  data.lidar_count = 0;
  data.lidar_range = 0;

  if (data.lidar_baseline > LIDAR_DETECT_THRESHOLD) {

    Log.Info(P("Lidar started - Baseline: %dcm"), data.lidar_baseline);
  } else {
    data.lidar_baseline = 0;
    Log.Error(P("Lidar initialisation failed - sensor disabled"));
  }

  update_lidar();
}

int get_lidar_baseline(int variance) {
  /**
  * Establish the baseline range from the lidar to the ground
  * The sensor will take samples until the readings are consistent
  * :variance: Max allowed variance of the baseline in cm
  * :return: Average variance of the baseline in cm
  */
  int average_range = get_lidar_range();
  int baseline_reads = 1;
  int average_variance = 500;

  // Keep reading in the baseline until it stablises
  while ((baseline_reads < MIN_BASELINE_READS || average_variance > variance) &&
         baseline_reads < MAX_BASELINE_READS) {
    int new_range = get_lidar_range();
    int new_variance = abs(average_range - new_range);

    average_variance = ((average_variance + new_variance) / 2);
    average_range = ((average_range + new_range) / 2);

    Log.Debug(P("Lidar Calibration: Range - %d, Variance - %d"),
              int(average_range), average_variance);
    baseline_reads++;
    delay(BASELINE_READ_INTERVAL);
  }

  // Calibration fails if the range is varying too much
  if (average_variance > variance) {
    average_range = -1;
  }

  return average_range;
}

int get_lidar_range() {
  /**
  * Get the range in cm from the lidar
  * :return: Target distance from sensor in cm
  */
  int target_distance = lidar.getDistance();
  Log.Verbose(P("Lidar Range: %d cm"), target_distance);
  return target_distance;
}

void update_lidar() {
  /**
  * Check the lidar to see if a traffic event has occurred.
  * Traffic events are counted as a break in the sensor's 'view' of the ground.
  * Any object between the sensor and the ground baseline will cause the sensor
  * to register a shorter range than usual.
  */
  data.lidar_range = get_lidar_range();

  // Detection occurs when target breaks the LoS to the baseline
  if ((data.lidar_baseline - data.lidar_range) > RANGE_DETECT_THRESHOLD) {

    // If x in a row
    if (successive_lidar_detections == MIN_SUCCESSIVE_LIDAR_READS) {
      successive_lidar_detections += 1;

      // Increase traffic count
      data.lidar_count++;
      Log.Info(P("Traffic count - Lidar: %d counts"), data.lidar_count);

      // Also send an XBee alert
      trigger_traffic_event();
    }

    else if (successive_lidar_detections < MIN_SUCCESSIVE_LIDAR_READS) {
      successive_lidar_detections += 1;
    }
  }

  else {
    successive_lidar_detections = 0;
  }
}

////////////////////////////////////////////////////////////////////////////////
/* RTC */

void start_rtc() {
  /**
  * Start up the real-time clock
  */
  rtc.begin();
  update_timestamp();

  timer.setInterval(SYSTEM_CLOCK_UPDATE_INTERVAL, update_system_clock);
  update_system_clock();
}

void update_timestamp() {
  /**
  * Read the timestamp into the current entry
  */

  get_datetime(data.timestamp);
  Log.Debug(P("Time: %s"), data.timestamp);
}

long get_timestamp() {
  /**
  * Get the current timestamp.
  * :return: Long timestamp format (seconds since 2000-01-01)
  */
  DateTime now = rtc.now();
  return now.secondstime();
}

void get_datetime(char *buffer) {
  /** Get the datetime in string format
  * DateTime follows the standard ISO format ("YYYY-MM-DD hh:mm:ss")
  * @param buffer Character buffer to write datetime to; Must be at least 20
  * char wide.
  */
  DateTime now = rtc.now();

  // Get the DateTime into the standard, readable format
  sprintf(buffer, P("%04d-%02d-%02d %02d:%02d:%02d"), now.year(), now.month(),
          now.day(), now.hour(), now.minute(), now.second());
}

void update_system_clock() {
  /**
  * Update the system clock of the Yun to match the RTC
  */
  DateTime now = rtc.now();
  uint32_t unix_time = now.unixtime();

  const char TIMESTAMP_HEADER[] = "\"id\":\"Time\",\"data\":";
  Log.Info("%c{%s%l}%c", PACKET_START, TIMESTAMP_HEADER, unix_time, PACKET_END);
}

////////////////////////////////////////////////////////////////////////////////
/* Bluetooth Scanner */

void start_bluetooth_scanner() {
  /** Start the bluetooth scanner
  * Initialise the bluetooth module in AP -> Master mode to scan for passing
  * devices.
  * Inquiry time is configurable and the results can be filtered by BT class.
  */

  Log.Debug(P("Starting Bluetooth at %d baud"), BLUETOOTH_BAUD);
  bluetooth.begin(BLUETOOTH_BAUD);
  bluetooth.listen();

  // Put BT module into master mode for scanning
  Log.Debug(P("Entering config..."));
  bluetooth.write(P("$$$"));
  bluetooth.flush();
  Log.Debug(P("Response: %s\n"), bluetooth.readString().c_str());

  Log.Debug(P("Setting master mode..."));
  bluetooth.write(P("SM,1\n"));
  bluetooth.flush();
  Log.Debug(P("Response: %s\n"), bluetooth.readString().c_str());

  // Set up regular scanning intervals
  timer.setInterval(BLUETOOTH_SCAN_INTERVAL, start_bluetooth_scan);
}

void start_bluetooth_scan() {
  /** Initiliase a bluetooth device scan
  * Scan for nearby bluetooth networks.
  * The module will produce a list of devices when the specified scan duration
  * has elapsed.
  */

  read_bluetooth_buffer();
  stop_bluetooth_read();

  // Start the scan
  Log.Debug(P("Starting scan"));
  bluetooth.write(P("I,"));
  bluetooth.println(BLUETOOTH_SCAN_TIME);

  Log.Debug(P("Response: %s"), bluetooth.readString().c_str());

  // Create a callback to grab the list when the module is finished scanning
  timer.setTimeout(BLUETOOTH_SCAN_TIME_MS, start_bluetooth_read);
}

void start_bluetooth_read() {
  bluetooth_recording = true;
  bluetooth_index = 0;
  bluetooth.listen();
  read_bluetooth_buffer();
}

void read_bluetooth_buffer() {
  if (bluetooth_recording) {

    while (bluetooth.available()) {

      String string = bluetooth.readString().c_str();
      for (size_t i = 0; i < string.length(); i++) {
        if (bluetooth_index < BLUETOOTH_BUFFER_SIZE) {
          bluetooth_buffer[bluetooth_index] = string[i];
          bluetooth_index++;

        } else {
          bluetooth_index = BLUETOOTH_BUFFER_SIZE - 1;
        }
      }
    }

    timer.setTimeout(BLUETOOTH_CHECK_INTERVAL, read_bluetooth_buffer);
  }
}

void stop_bluetooth_read() {
  bluetooth_recording = false;
  bluetooth_buffer[bluetooth_index] = '\0';

  const char BLUETOOTH_HEADER[] = "\"id\":\"Blue\",\"data\":";
  Log.Info(P("%c{%s\"%s\"}%c"), PACKET_START, BLUETOOTH_HEADER, bluetooth_buffer,
           PACKET_END);
}

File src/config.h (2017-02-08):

#include "Arduino.h"
#include <Logging.h>

///////////////////////////////////////////////////////////////////////////////
// Unit
const int SSL_TESTBED_VERSION = 9;
const byte UNIT_ID = 1;
const char UNIT_NAME[] = "Quezacoatl";

// Use Serial for debug; Serial1 for normal operation
#define USE_SERIAL Serial1
const int LOGGER_LEVEL = LOG_LEVEL_INFOS;

// Misc
    const bool REAL_TIME_CLOCK_ENABLED = true;
const bool CURRENT_MONITOR_ENABLED = false;
const bool LAMP_CONTROL_ENABLED = false;

// Comms
const bool BLUETOOTH_ENABLED = true;
const bool XBEE_ENABLED = false;

// Traffic
const bool PIR_ENABLED = true;
const bool LIDAR_ENABLED = true;
const bool THERMO_FLOW_ENABLED = false;

// Comms
const int YUN_BOOT_DELAY = 5000; //Time to wait for Yun to boot up before checking the handshake
const long YUN_LINUX_BAUD_RATE = 250000;
const int COMM_BUFFER_SIZE = 250;
const int BLUETOOTH_BUFFER_SIZE = 300;

const long SERIAL_BAUD = 57600;

// XBee Socket
const long XBEE_BAUD = 9600;
enum XBEE_1_COMMS{
    UART = 0,
    SPI = 1
};
const byte XBEE_1_MODE = UART;

// XBee Socket 2 - Bluetooth module
const long BLUETOOTH_BAUD = 9600;


///////////////////////////////////////////////////////////////////////////////
// Pin assignments
const byte YUN_RX = 0;  // Unused Pin - Tied to USB UART
const byte YUN_TX = 1;  // Unused Pin - Tied to USB UART
const byte SPI_ATTN = 4;    // SPI Attention pin for XBEE-SPI comms
const byte SPI_SS = 5;  // SPI Slave Select
const byte LAMP_CONTROL_PIN = 6;    // Lamp control - uses PWM with inverse duty cycle
const byte YUN_HANDSHAKE_PIN = 7;   // Yun handshake - HIGH when Yun is busy/booting
const byte XBEE_SLEEP_PIN = 8;  // XBEE sleep pin; Bring HIGH to allow XBEE comms
const byte WIDE_PIR_PIN_L = 9;  // PIR motion detect pin; pulled HIGH when motion is detected
const byte COMM_2_TX = 10;  // Send pin for XBEE socket 2; UART-only
const byte COMM_2_RX = 11;  // Receive pin for XBEE socket 2; UART-only
const byte LIDAR_PWM_PIN = 12;  // Data pin for LIDARLite
const byte LIDAR_TRIGGER_PIN = 13;  // PWM Trigger pin for LIDARLite
const byte COMM_1_RX = 14;  // Send pin for XBEE socket 1; UART and SPI compatible
const byte COMM_1_TX = 16;  // Receive pin for XBEE socket 1; UART and SPI compatible

const byte WIDE_PIR_PIN_R = A0;  // Sonar receive pin - can use pulse width or ADC for distance measurements
const byte NARROW_PIR_PIN = A1;
const byte HUMIDITY_PIN = A3;   // Humidity level pin - Gives ADC humidity level
const byte TEMPERATURE_PIN = A4;    // Temperature data pin for DS18B20 digital temperature probe
const byte CURRENT_DETECT_PIN = A5; // Current monitor pin for current clamp - gives offset ADC current wave


///////////////////////////////////////////////////////////////////////////////
// Timer

const int CHECK_FLOW_INTERVAL = 200;
const int FLOW_COOLDOWN = 2000; // Optical flow detection cooldown in ms

const int CHECK_RANGE_INTERVAL = 100;
const int RANGE_DETECT_THRESHOLD = 70; // Minimum threshold for range detection in cm. (Target must move at least this much)

const int LIDAR_CHECK_RANGE_INTERVAL = 100;
const int LIDAR_DETECT_THRESHOLD = 50;

const long PRINT_INTERVAL = 60000;
const long CHECK_ENVIRONMENTAL_SENSOR_INTERVAL = PRINT_INTERVAL/2;
const long XBEE_TRANSMIT_INTERVAL = PRINT_INTERVAL; // Time between XBee transmissions
const long SYSTEM_CLOCK_UPDATE_INTERVAL = 60000;

const int BLUETOOTH_SCAN_TIME = 5;  // Bluetooth scan duration in seconds
const long BLUETOOTH_SCAN_TIME_MS = BLUETOOTH_SCAN_TIME * 1000; // Length of a bluetooth scan in milliseconds
const long BLUETOOTH_SCAN_INTERVAL = BLUETOOTH_SCAN_TIME_MS + 6000; // Time between bluetooth scans in milliseconds
const long BLUETOOTH_CHECK_INTERVAL = 20;  // Time between bluetooth response checks
const long BLUETOOTH_SERIAL_WAIT = 1000;


///////////////////////////////////////////////////////////////////////////////
// Real-time Clock

const int DATETIME_WIDTH = 20;

///////////////////////////////////////////////////////////////////////////////
// Sonar/Lidar
const byte MIN_BASELINE_READS = 20; // Minimum number of reads needed to establish a baseline
const byte MAX_BASELINE_READS = 30; // Maximum number of reads to establishe a baseline
const int BASELINE_READ_INTERVAL = 200; // Time between range baseline calibration reads in milliseconds
const int BASELINE_VARIANCE_THRESHOLD = 20; // Maximum acceptable range sensor baseline error in cm.
const byte MIN_SUCCESSIVE_LIDAR_READS = 0;  // Number of consecutive lidar reads that will result in a 'detection'

///////////////////////////////////////////////////////////////////////////////
// PIR

enum PIR_TYPE{
    PIR_WIDE = 0,
    PIR_NARROW = 1
};

enum PIR_SIDE_INDEX{
    PIR_WIDE_LEFT = 0,
    PIR_WIDE_RIGHT = 2
};
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

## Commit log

2015-08-14 Initial commit - All sensors added
    Still need XBee and current sensor hardware
    [Street_Fighter_v1.0.brd, Street_Fighter_v1.0.sch, Street_Fighter_v1.1.brd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]
2016-01-14 V5 Update
    Added 3D printed parts
    V5 - Trialling new Sonar detection algorithm
    - Sonar must have 2 consecutive detections to register
    PIR timeout changed from 5s to 2s.
    [BH1750_mount.skp, BH1750_mount.stl, Big shell.skp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]
2016-01-22 Added debug mode to code
    We're actually up to version 6
    - Fixed the angular printed mount for lidar
    [Big shell.skp]
2016-01-29 Fixed Sonar counting
2016-02-22 Version 8 - Refactored code to use data structure instead of JSON - Added dimming functions - Fixed JSON Printing
    [SSLTestbed.ino, config.h]
2016-02-22 Added support for both TMP36 and DS18B20 - Change temperature sensor type in the config file
2016-02-23 Fixed memory leak - Print to XBee function is broken - Added quick function to logging to get the log level
    [SSLTestbed.ino, config.h]
2016-02-24 Fixed memory leak with xbee buffer - Buffer now deallocates after use * Dynamic memory allocation is prohibited on aviation software where it could cause a safety issue * May need to make all buffers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
    [SSLTestbed.ino]
2016-02-26 Converted dynamic buffers to static - Some sensors start with an update so no data is missing after a restart - Changed temperature sensor over to DS18B20
    [SSLTestbed.ino, config.h]
2016-04-14 Added license. Ignoring SKB files
    [BH1750_mount.skp, BH1750_mount.stl, Big shell.skp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]
2016-04-18 Removed XBEE API code; now using transparent mode
    [Street_Fighter_v1.1.brd, Street_Fighter_v1.1.sch]
2016-04-29 Fixes Issue #2 and Issue #4. New XBee socket + SPI
    [Street_Fighter_v1.1.brd, Street_Fighter_v1.1.sch, Street_Fighter_v1.2.brd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]
2016-04-29 Switched to adafruit RTC library
2016-04-29 Fixed sonar pin assignment
    [SSLTestbed.ino]
2016-04-29 Removed unused sonar library
2016-05-10 Added spare header to board
    [Street_Fighter_v1.2.sch]
2016-05-11 Added arduino badge
2016-06-07 StreetFighter v1.3 board - Fixed bad pin assignments for SoftSerial
    [Street_Fighter_v1.2.sch, Street_Fighter_v1.3.brd, Street_Fighter_v1.3.sch]
2016-06-10 Added flags for optional sensors
2016-06-16 Added analog sonar option; hopefully fixed bluetooth scanning
    [SSLTestbed.ino, config.h]
2016-08-18 Fixed sonar reads - Sonar now only performs compensation in pulseIn mode - There may be bugs in the compensation algorithm due to numerical overflows - Analog measurements just follow the usual scali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
    [Street_Fighter_v1.2.brd, Street_Fighter_v1.2.sch]
2016-11-16 Updated mounting plate for traffic sensors. Also started adding in the possibility for more than 2 PIR sensors.
    [Luminaire Mounting Plates.skp, Street_Fighter_v1.4.brd, Street_Fighter_v1.4.sch]
2016-11-16 Fixed up some import errors; not completely
    [SSLTestbed.ino, config.h]
2016-11-17 Fixed up PIR sensor behaviour
    [SSLTestbed.ino, config.h]
2017-02-08 Cleaned up redundant libraries
    [Luminaire Mounting Plates.skp]

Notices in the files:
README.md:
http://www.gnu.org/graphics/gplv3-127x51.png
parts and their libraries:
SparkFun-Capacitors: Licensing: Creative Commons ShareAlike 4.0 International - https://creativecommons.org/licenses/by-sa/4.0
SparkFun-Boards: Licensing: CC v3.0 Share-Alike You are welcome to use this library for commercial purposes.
